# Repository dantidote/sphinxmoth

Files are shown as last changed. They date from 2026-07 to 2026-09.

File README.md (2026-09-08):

# Sphinxmoth

### The little board that answers the iSphynxII: a working flash mod for FireWire iPods (1st/2nd gen)

An **active FPGA interposer** that lets flash storage (CF, or SD behind an adapter) fully replace the 1.8″ hard drive in a **1st/2nd-generation
iPod**: boot, standalone playback, **and full-speed FireWire restore + iTunes sync**.

This is the first time in the ~25 years since these iPods shipped
that all of that works at once on flash storage. Passive adapters never could, and
it turns out they never could have. The reason was documented by Texas
Instruments in 2001.

A note on qualifications: I had none. This is the first PCB I've ever had
made, I leaned on the autorouter more than any self-respecting layout
engineer would admit, and before this project I'd never programmed an FPGA.
This board isn't pretty; it was never meant to be. It exists to answer one
question: is this possible at all?

| | |
|---|---|
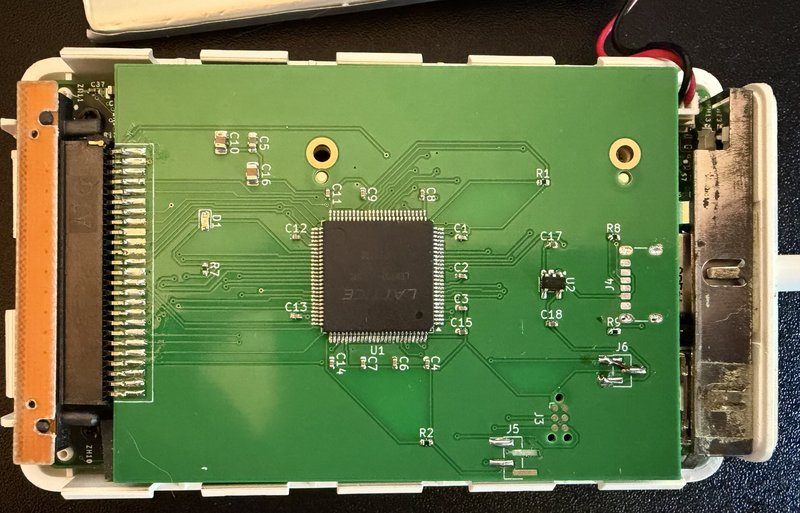
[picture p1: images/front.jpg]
front
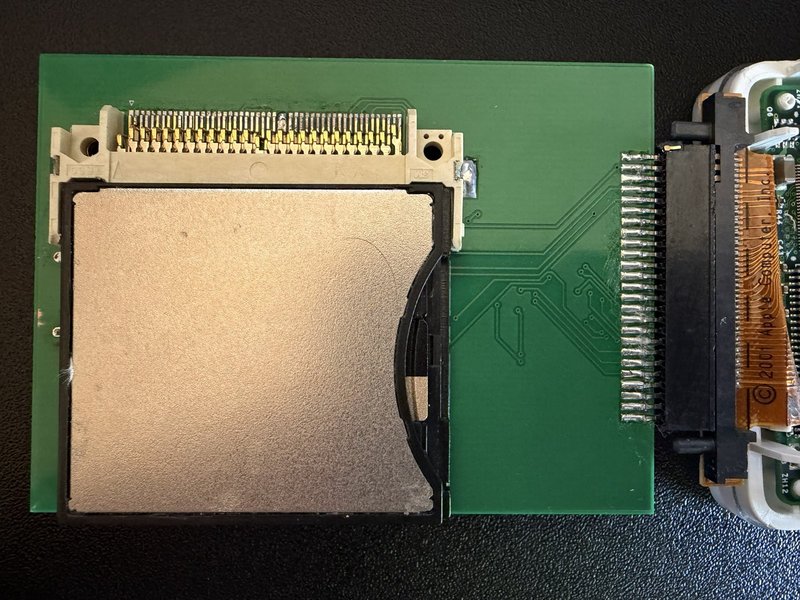
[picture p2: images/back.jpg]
back
|  |  |

*The assembled v1 board: FPGA side and CF side. And the point of it all:*

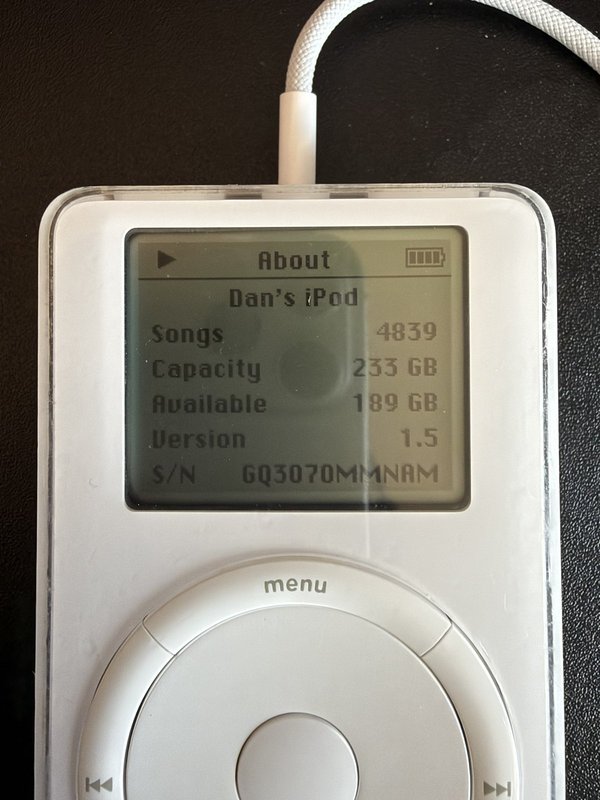
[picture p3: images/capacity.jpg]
iPod About screen: 256 GB


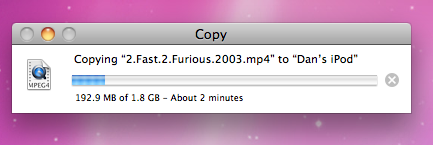
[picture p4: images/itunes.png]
Copying a 1.8 GB file to the iPod over FireWire, about 2 minutes


<p align="center"><i>A 1.8 GB file at roughly 15 MB/s over FireWire, through the bridge. No, the
1st gen can't play it. That's not the point.</i></p>

## Buying an assembled board

Sphinxmoth is open source and stays that way: the gerbers, BOM, gateware and
a hardware-validated bitstream are all in this repo, under licenses (MIT and
CERN-OHL-P-2.0) that let you build your own, and sell them if you want to.
Please do.

If you would rather not order a PCB, source a MachXO2, and go find a JTAG
probe, I sell **pre-assembled, pre-flashed boards** at
**[wunkuslabs.com](https://wunkuslabs.com/products/sphinxmoth)**.

## Why the cheap green CF/IDE adapters never worked

FireWire-era iPods (1G/2G, and the 3G) use TI's **TSB43AA82 "iSphynxII"**
FireWire-to-ATA bridge. From TI's own *TSB43AA82 Storage Reference Design*:

> It should be noted that iSphynxII does not implement the 16-bit CRC value
> required at the end of ATA ultraDMA transfers. There are two ways to deal
> with this. The first is to use HDDs that allow transfers to continue even if
> the correct CRC value is not received. The second is to insert an ASIC/PLD
> between iSphynxII and the HDD that calculates the CRC as the transfer is
> taking place and drives it to the drive at the appropriate time. This
> reference design assumes the HDD does not require the CRC.

Apple took TI's first option: the original Toshiba 1.8″ drives tolerate the
missing CRC. **Every CF card enforces it.** So the moment a flash device sees
an Ultra-DMA burst from the iSphynxII, it (correctly) rejects the transfer with
an interface-CRC error, and no passive adapter can ever fix that, because the
CRC simply isn't on the wire.

**This project is the "ASIC/PLD between iSphynxII and the HDD" that TI
described, built 25 years later.** A Lattice MachXO2 sits in the datapath,
re-originates every UDMA burst, and supplies the CRC the iSphynxII omits.

But the CRC is only the first wall. Credit to Reddit user **SquashHour9940**,
whose excellent investigation
([*Further research about flash modified iPod 1st/2nd Gen syncing problem*](https://www.reddit.com/r/ipod/comments/18fujac/further_research_about_flash_modified_ipod_1st2nd/))
independently mapped two more layers:

2. **Removable vs. fixed media**: consumer CF cards report themselves as
   *removable media*; the iPod firmware and iTunes want a *fixed disk*.
   Industrial CF cards (fixed-disk firmware) get past this gate; consumer
   cards don't.
3. **The TSB43AA82 falls back to slow PIO when it detects a CF card**:
   staged 1 MB at a time through the iPod's tiny SRAM, capping passive-adapter
   FireWire transfers around 300 KB/s even when everything else works.

And our bring-up found a fourth layer nobody had hit before, because nobody
had gotten this far:

4. **The PP5002 CPU (the retail OS) is a DMA host too**: its UDMA write
   strobes are electrically hostile (ringing, data-dependent crosstalk) and
   corrupted the filesystem on every standalone boot until this bridge learned
   to detect that master and quietly demote it to PIO.

This bridge defeats all four: it originates the missing CRC, rewrites the
card's IDENTIFY on the wire (media type and DMA capabilities, per master;
a removable or CFA-signature word 0 becomes a classic fixed-disk value,
checksum corrected), keeps the DMA path alive at full speed, and gives
each of the iPod's two very different bus masters the bus discipline it
actually needs. The fixed-disk rewrite has been tested end-to-end with a
retail Lexar Professional 800x (32 GB, UDMA 7), the exact card class the
community documented as removable-reporting: it restores and syncs
through the bridge like any industrial card.

## Status

| | |
|---|---|
| **v1 board** (CF slot, `board/`) | **Working.** Boots, plays, restores, syncs. Reads 19 MB/s, writes 4.6 MB/s over FireWire. Running a 256 GB SD (via FC1307A CF adapter) today. |
| Validated bitstream | `releases/v1.0-first-music/` (build outputs are not run-deterministic; this exact binary is the hardware-proven one) |
| **v2** (native microSD) | **Being considered.** microSD would be nice, but at first glance it needs a larger/more expensive FPGA (the v1 XO2-2000 is 89% full and the disk logic moves on-chip; the draft targets an XO2-7000). Exploratory work lives on the [`v2-native-sd`](../../tree/v2-native-sd) branch: unfabbed, unvalidated, promise-free. **Do not build it.** |

Tested on: iPod 1st gen (firmware 1.5), Transcend industrial 2 GB CF,
FC1307A SD-CF adapter + 256 GB SD, Mac OS X 10.6 + iTunes over FireWire.
2G/3G iPods use the same TSB43AA82 and *should* work; reports welcome.

## Rockbox

Rockbox runs on a Sphinxmoth iPod, with two board-specific wrinkles: the
Rockbox 4.0 release crashes at boot on every 1G/2G (an unaligned store in
the PP5002 scheduler, fixed upstream after 4.0), and Rockbox's stock IDE
timing is too fast for the `v1.1-mg132-fix3b` bridge image, which adds
about 45 ns to every register read through its PIO synchroniser (init fails
with `ATA error: -11` or `-32`). Newer bridge images pass PIO through the
raw pads and need nothing but the crash fix.

Everything Rockbox-related lives in its own repo:
[**sphinxmoth-rockbox**](https://github.com/dantidote/sphinxmoth-rockbox):
the ATA driver patch, tested builds for boards already in the field on
fix3b, and a workflow that rebuilds them on each upstream Rockbox release.
The same files are served from [wunkuslabs.com/guide](https://wunkuslabs.com/guide#rockbox).

## How it works (the short version)

The FPGA discovered during bring-up that it serves **three masters**, and it
gives each a different personality:

| Master | How it's detected | What it gets |
|---|---|---|
| **iSphynxII** (FireWire) | never issues `EXECUTE DIAGNOSTIC` | Full UDMA2 bridge: bursts re-timed through a FIFO, **end-of-burst CRC generated**, multi-burst writes, a deliberately "bouncy" flow-control throttle (it abandons bursts on long clean pauses) |
| **PP5002** (retail OS) | opens with `C90 EXECUTE DIAGNOSTIC` | IDENTIFY patched in flight (DMA capability words zeroed, checksum fixed) → the OS falls back to PIO `READ/WRITE MULTIPLE` through a transparent passthrough |
| **CF card** | n/a | Always runs UDMA2, regardless of what either host negotiated (`SET FEATURES` sector-count byte rewritten on the wire) |

Plus the small in-flight surgeries each master demanded: BSY served for status
polls mid-command, CS/DA forced idle at the card during bridged bursts, strict
data setup/hold on every strobe edge, spec-ordered burst termination, and
STANDBY/SLEEP commands rewritten to CHECK POWER MODE (retail cards honor them,
then never wake the way the OS expects; the original drive woke transparently). The
testbenches encode all of it: the card model sector-terminates, pauses,
checks CRC and enforces tSS; the host model parks on the status register,
polls, and rings its strobe line. Every cruelty in the sims reproduced a bug
first found on real hardware during a two-day, fourteen-bug bring-up.

## Building it

Or skip it: assembled, flashed and tested boards are
[for sale](https://wunkuslabs.com/products/sphinxmoth).

**Board (v1):** upload `board/ipod-cf-udma-gerbers.zip` to any fab (2 layer,
53×72 mm, 1.6 or 0.8 mm). CF socket (J2) is on the BACK; everything else on
the front. `board/BOM.csv` + `board/ipod-cf-udma-pos.csv` for assembly.

**Bitstream:** Lattice Diamond 3.14, `cd diamond && pnmainc rebuild.tcl` →
`impl1/ipodboard_impl1.jed`. Or just flash `releases/v1.0-first-music/`.

**Programming:** Tag-Connect TC2030-IDC-NL pads (J3, zero height) to any
JTAG probe Diamond Programmer / openFPGALoader speaks. The MachXO2 configures
from internal flash; program once, done.

**Power:** bus-powered from the iPod's 3.3 V. J6 shunt selects iPod (1-2) or
bench USB-C (2-3); never both. The green LED blips a slow heartbeat when idle
and flashes while data is moving through the bridge. The UART header (J5, 115200 8N1) streams the
gateware's event log; if something misbehaves, that log is the microscope
this whole project was debugged through.

**Simulation:** Icarus Verilog: `cd gateware && iverilog -g2012 -DSIM -I rtl
-o wr.vvp sim/tb_full_write.v rtl/*.v && vvp wr.vvp` (likewise
`tb_full_read.v`).

## Repository layout

| Path | Contents |
|---|---|
| `board/` | v1 board: KiCad project, fabbed gerbers, BOM, schematic PDF, DRC/ERC |
| `gateware/rtl/` | the bridge RTL (`interposer_top` + engines) |
| `gateware/sim/` | hardware-calibrated torture testbenches |
| `diamond/` | Lattice Diamond build project |
| `releases/` | hardware-validated bitstreams |
| `v2-native-sd` branch | exploratory native-microSD v2: board draft, `ata_device`/`sd_host` cores, design doc |

## Known v1 errata

- J2 pin 39 (−CSEL) must be grounded (already fixed in these gerbers).
- J2 pins 45/46 (−DASP/−PDIAG) float; some cards may care (10 k pull-ups to
  3.3 V recommended).
- The USB-C shield holes share the CF socket's courtyard; desoldering J4
  heat-stresses socket joints (ask us how we know). v2 deletes both parts.
- DD-bus ↔ control-line crosstalk exists at the margins; the gateware routes
  around it (PIO for the PP5002), v2 adds proper guarding.

## Credits

- **SquashHour9940** (r/ipod): the fixed-disk/removable-media and
  TSB43AA82-PIO-fallback research that mapped layers 2 and 3:
  https://www.reddit.com/r/ipod/comments/18fujac/further_research_about_flash_modified_ipod_1st2nd/
- Texas Instruments, for documenting in 2001 exactly which chip to blame
  and exactly what to build about it.
- [freerouting](https://github.com/freerouting/freerouting): the open-source
  autorouter that closed every net on both boards.

## License

Gateware and software: MIT. Hardware (schematics, board files, gerbers):
CERN-OHL-P-2.0. No warranty; a 25-year-old iPod is involved.

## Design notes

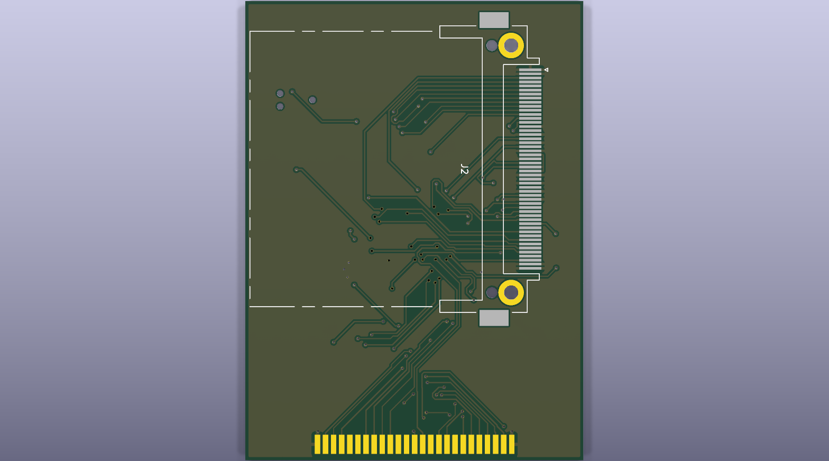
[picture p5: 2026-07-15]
board/board_bottom.png

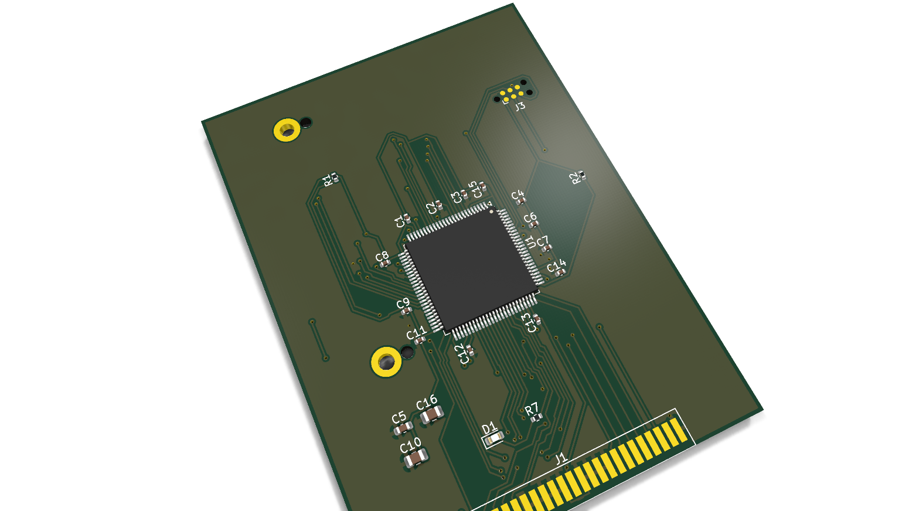
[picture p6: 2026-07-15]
board/board_persp.png

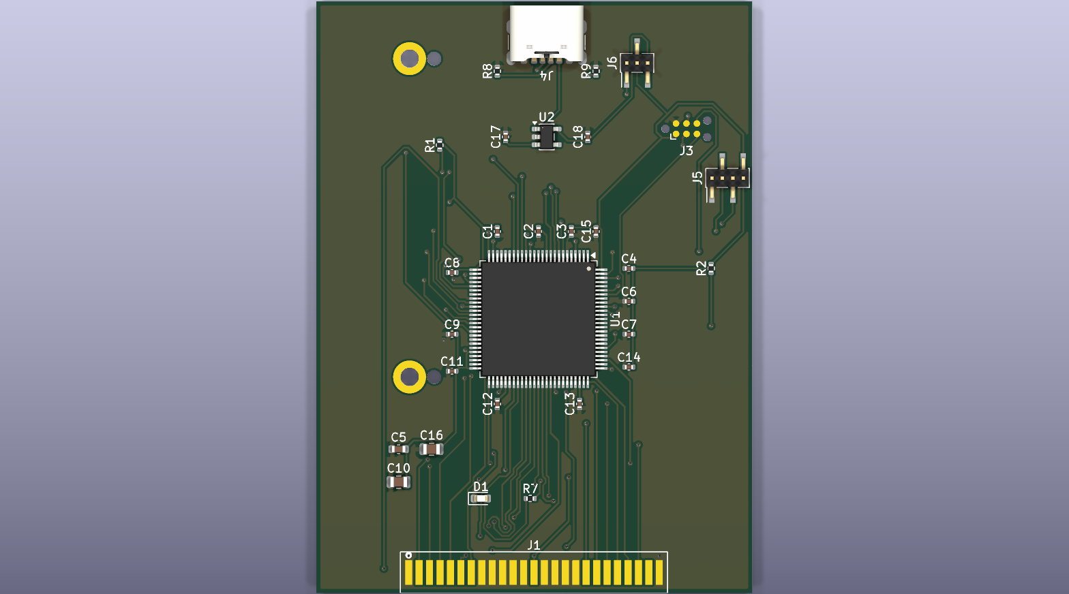
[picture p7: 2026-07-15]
board/board_top.png

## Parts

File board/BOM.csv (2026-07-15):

Refs | Value | Footprint | MPN | Qty
C1-C4,C6-C9,C11-C14 | 100nF | Capacitor_SMD:C_0402_1005Metric | CL05B104KO5NNNC | 12
C5 | 4.7uF | Capacitor_SMD:C_0603_1608Metric | CL10A475KO8NNNC | 1
C10,C16 | 10uF | Capacitor_SMD:C_0805_2012Metric | C2012X5R1E106K125AB | 2
C15,C17,C18 | 1uF | Capacitor_SMD:C_0402_1005Metric | CL05A105KA5NNNC | 3
D1 | LED | LED_SMD:LED_0603_1608Metric | 150060GS75000 | 1
J1 | iPod_1.8in_50pin | interposer:iPod_1.8in_50pin | SPECIALTY-iPod-1.8in-50pin | 1
J2 | CF True-IDE socket | Connector_Card:CF-Card_3M_N7E50-E516xx-30 | N7E50-E516PK-30 | 1
J4 | USB-C | Connector_USB:USB_C_Receptacle_GCT_USB4125-xx-x_6P_TopMnt_Horizontal | USB4125-GF-A-0190 | 1
R1,R2 | 10k | Resistor_SMD:R_0402_1005Metric | CRCW040210K0FKED | 2
R7 | 330R | Resistor_SMD:R_0402_1005Metric | RC0402FR-07330RL | 1
R8,R9 | 5.1k | Resistor_SMD:R_0402_1005Metric | RC0402FR-075K1L | 2
U1 | LCMXO2-2000HC-4TG100C | Package_QFP:TQFP-100_14x14mm_P0.5mm | LCMXO2-2000HC-4TG100C | 1
U2 | AP2112K-3.3 | Package_TO_SOT_SMD:SOT-23-5 | AP2112K-3.3TRG1 | 1

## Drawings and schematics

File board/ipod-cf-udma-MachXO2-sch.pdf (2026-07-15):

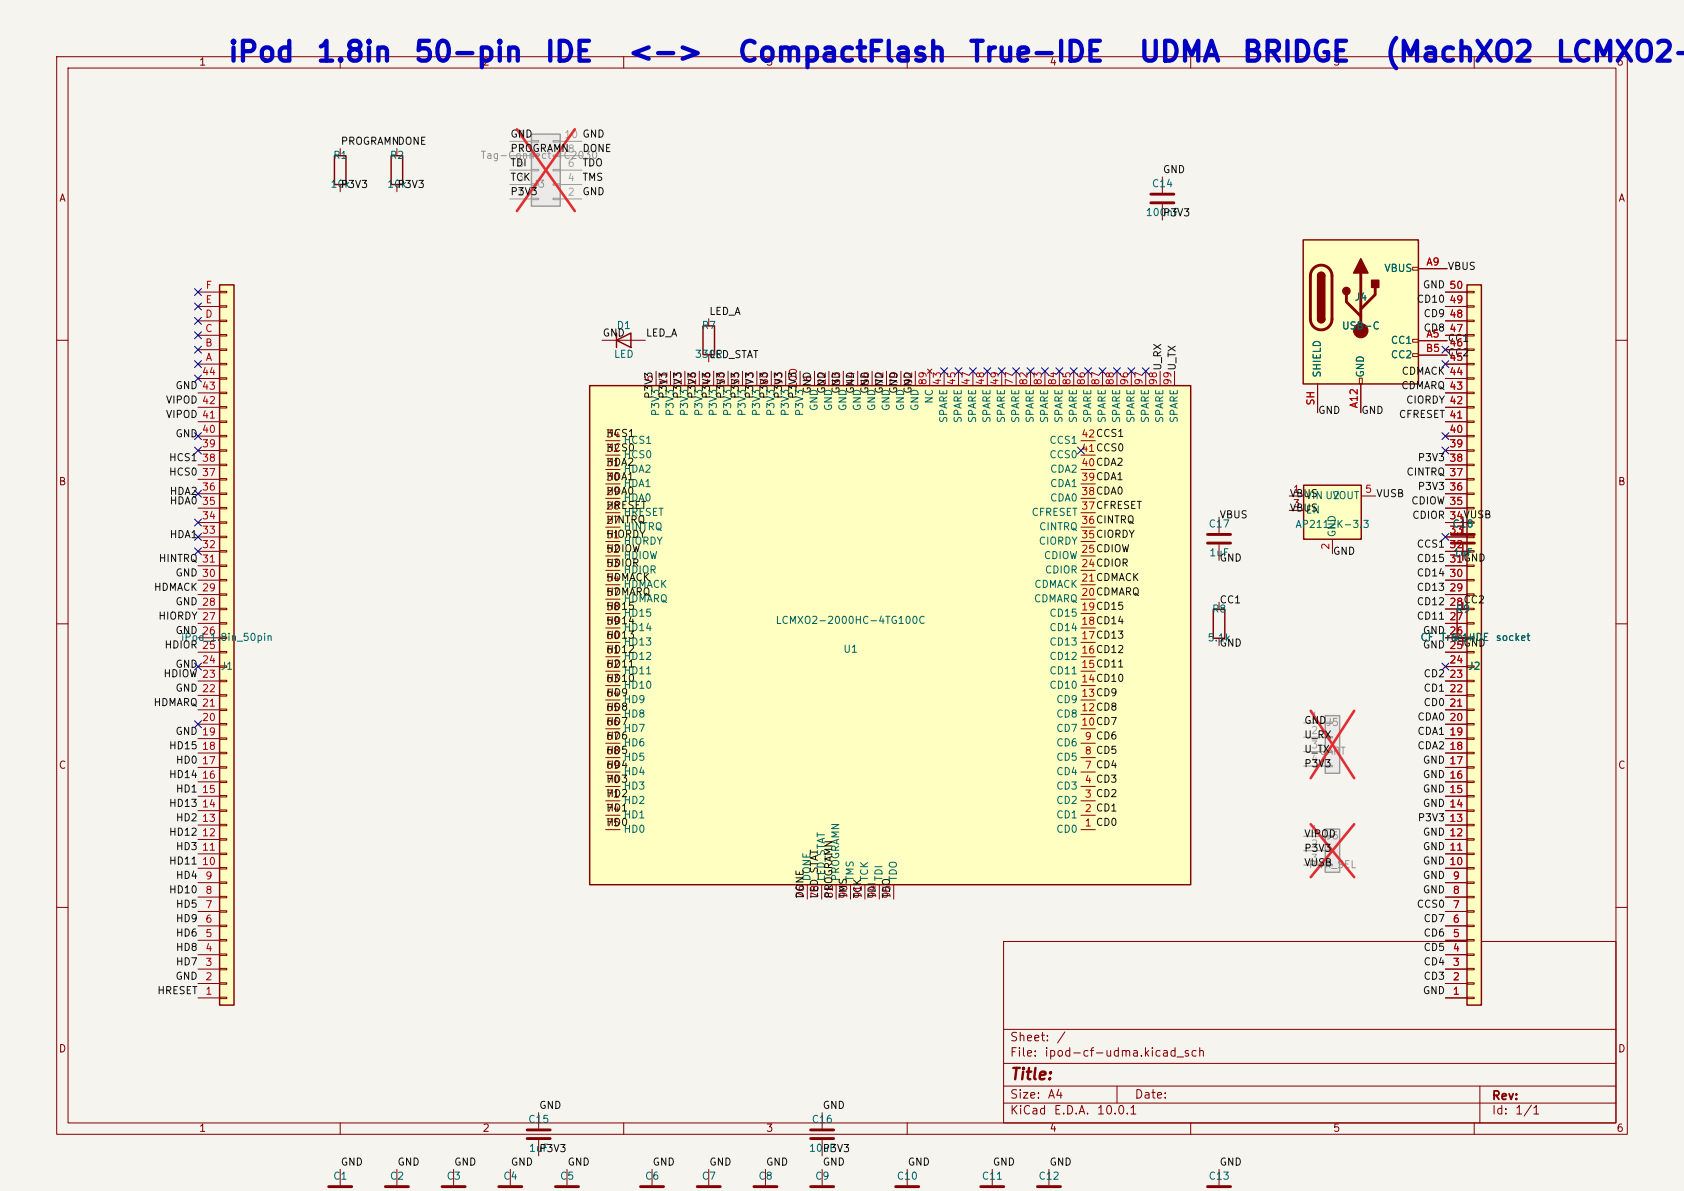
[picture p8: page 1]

iPod 1.8in 50-pin IDE <-> CompactFlash True-IDE UDMA BRIDGE (MachXO2 LCMXO2-2000HC-TG100)

GND
CCS0 GND HD1 HD0 GND
HCS1
CD12 CD13 CD14 UDMA / CRC: U1 (MachXO2) actively re-times the bus and is the device the iPod talks to. The FPGA HDL terminates the host UDMA burst, and on writes may IGNORE / force-OK the host-supplied CRC while regenerating a correct CRC toward the CF card. A purely passive adapter CANNOT do this - that is why an FPGA sits in the datapath.
HDIOW

6 CD4 7 CD5 8 CD6 9 CD7 10 P3V3 11 CD8 12 CD9 13 CD10 14 CD11 15 CD12 16 CD13 17 CD14 18 CD15 19 CDMARQ 20 CDMACK 21 GND 22 P3V3 23 CDIOR 24 CDIOW 25 P3V3 26 HINTRQ 27 HRESET 28 HDA0 29 HDA1 30 HDA2 31 HCS0 32 GND 33 HCS1 34 CIORDY 35 CINTRQ 36 CFRESET 37 CDA0 38 CDA1 39 CDA2 40 CCS0 41 CCS1 42 SPARE 43 GND 44 SPARE 45 P3V3 46 SPARE 47 SPARE 48 SPARE 49 P3V3 50 HIORDY 51 HDIOW 52 HDIOR 53 HDMACK 54 P3V3 55 GND 56 HDMARQ 57 HD15 58 HD14 59 HD13 60 HD12 61 HD11 62 HD10 63 HD9 64 HD8 65 HD7 66 HD6 67 HD5 68 HD4 69 HD3 70 HD2 71 GND 72 P3V3 73 HD1 74 HD0 75 DONE 76 SPARE 77 LED_STAT 78 GND 79 P3V3 80 PROGRAMN 81 SPARE 82 SPARE 83 SPARE 84 SPARE 85 SPARE 86 SPARE 87 SPARE 88 NC 89 TMS 90 TCK 91 GND 92 P3V3 93 TDI 94 TDO 95 SPARE 96 SPARE 97 SPARE 98 SPARE 99 P3V3100 U1
HCS0 HCS1 P3V3 P3V3

HD0 HD1 HD2 HD3 HD4 HD5 HD6 HD7 HD8 HD9 HDIOR HIORDY HDMACK HINTRQ

J2 CF True-IDE socket PWR1 PWR_FLAG

Sheet: /
File: ipod-cf-udma.kicad_sch
Title:

Size: A4 | Rev:
KiCad E.D.A. 10.0.1 | Id: 1/1

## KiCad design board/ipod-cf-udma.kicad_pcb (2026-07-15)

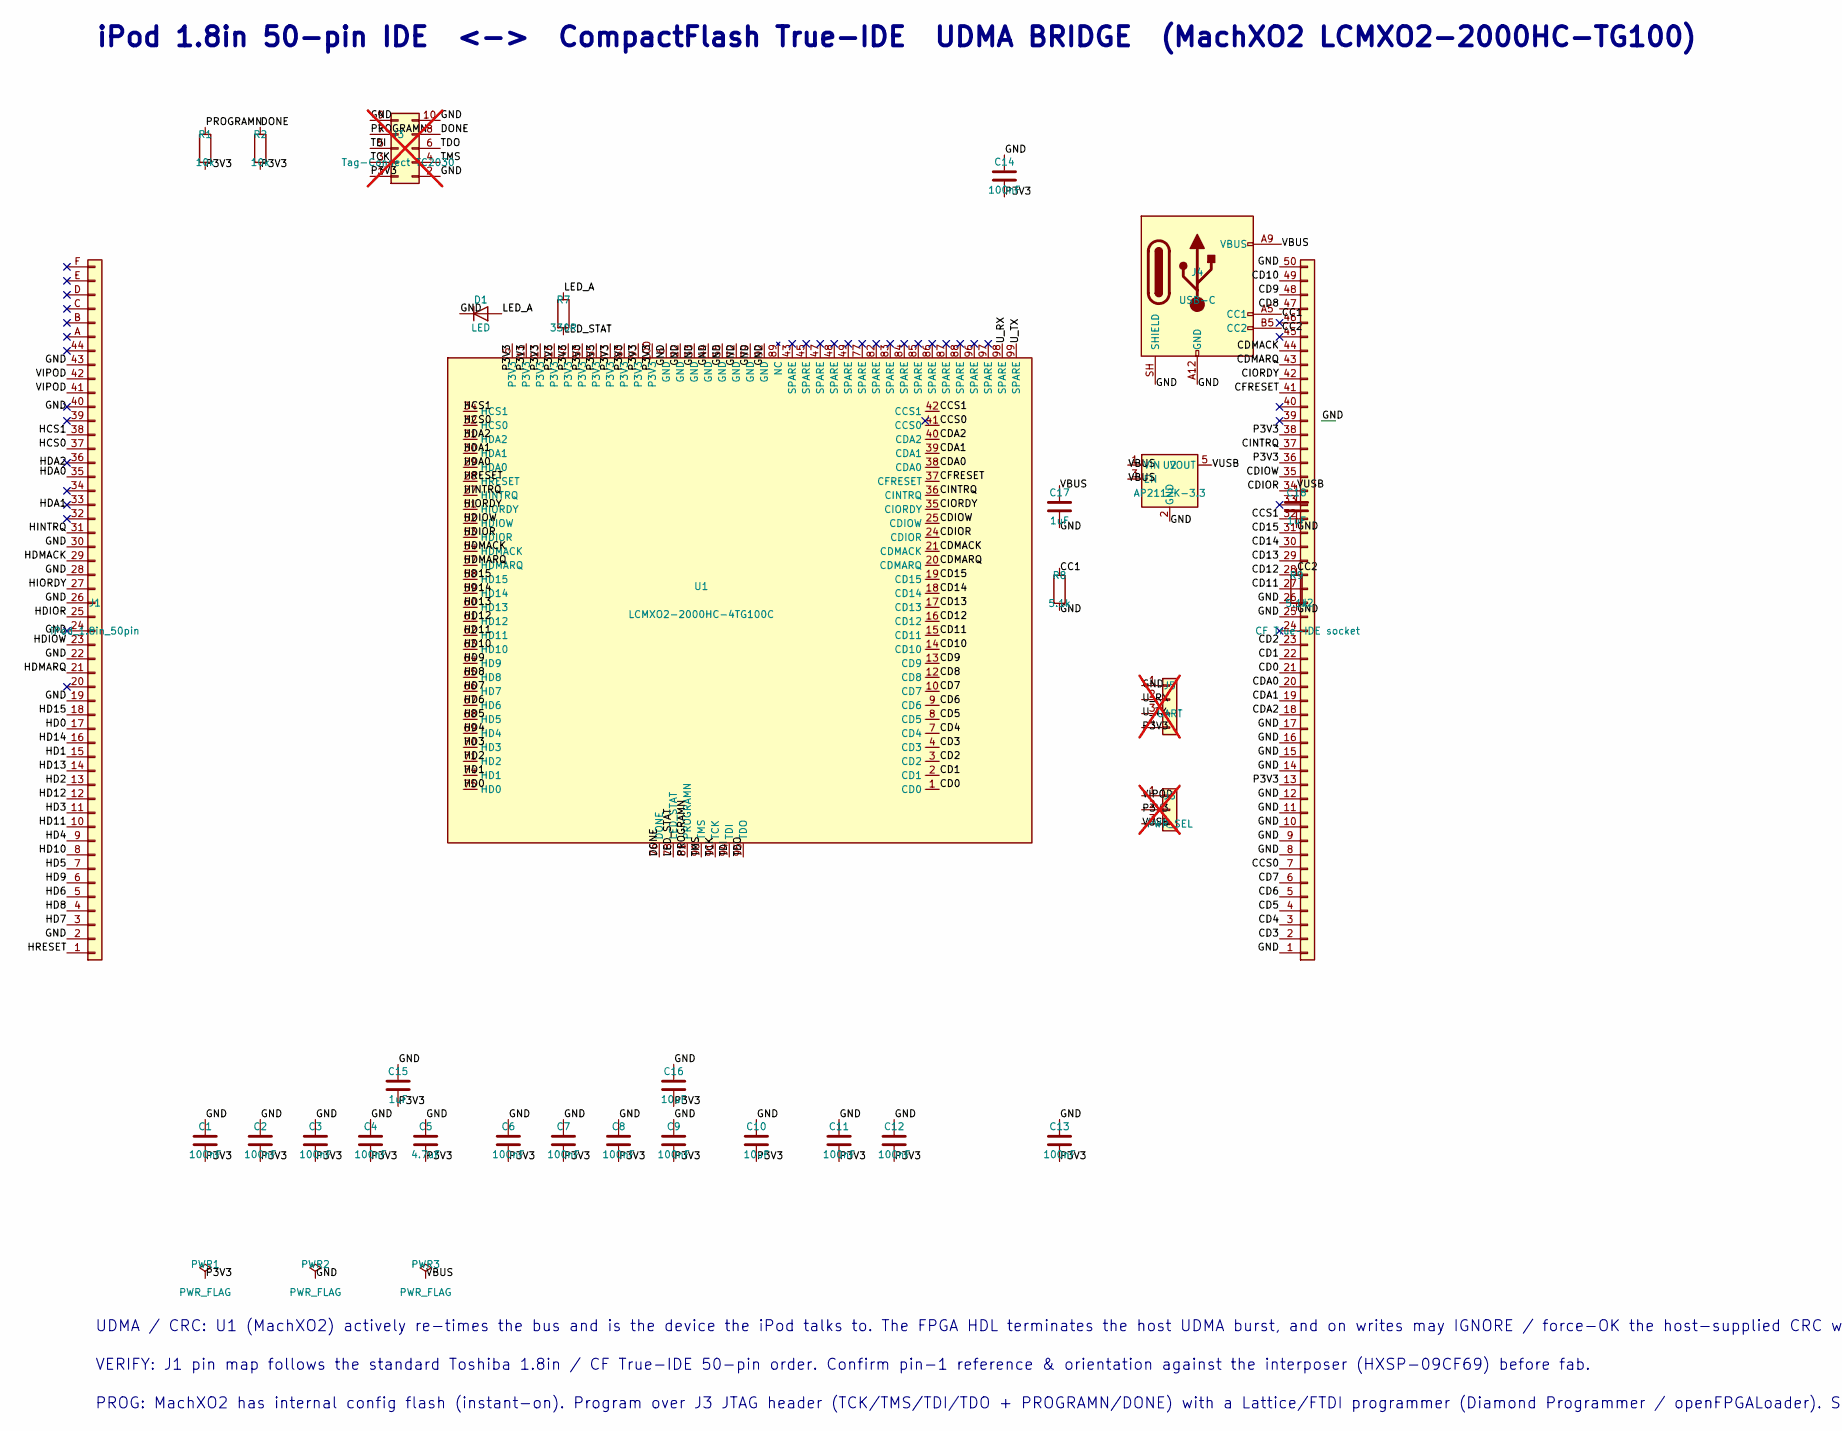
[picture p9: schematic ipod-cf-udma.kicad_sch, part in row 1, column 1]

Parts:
C1, C2, C3, C4, C6, C7, C8, C9, C11, C12, C13, C14: 100nF; C_0402_1005Metric; MPN CL05B104KO5NNNC
C5: 4.7uF; C_0603_1608Metric; MPN CL10A475KO8NNNC
C10, C16: 10uF; C_0805_2012Metric; MPN C2012X5R1E106K125AB
C15, C17, C18: 1uF; C_0402_1005Metric; MPN CL05A105KA5NNNC
D1: LED; LED_0603_1608Metric; MPN 150060GS75000
J1: iPod_1.8in_50pin; MPN SPECIALTY-iPod-1.8in-50pin
J2: CF True-IDE socket; CF-Card_3M_N7E50-E516xx-30; MPN N7E50-E516PK-30
J3: Tag-Connect TC2030; Tag-Connect_TC2030-IDC-NL_2x03_P1.27mm_Vertical; MPN DNP-padsonly; not fitted
J4: USB-C; USB_C_Receptacle_GCT_USB4125-xx-x_6P_TopMnt_Horizontal; MPN USB4125-GF-A-0190
J5: UART; PinHeader_1x04_P1.27mm_Vertical_SMD_Pin1Left; MPN DNP-optional-header; not fitted
J6: PWR_SEL; PinHeader_1x03_P1.27mm_Vertical_SMD_Pin1Left; MPN DNP-solderjumper; not fitted
PWR1, PWR2, PWR3: PWR_FLAG
R1, R2: 10k; R_0402_1005Metric; MPN CRCW040210K0FKED
R7: 330R; R_0402_1005Metric; MPN RC0402FR-07330RL
R8, R9: 5.1k; R_0402_1005Metric; MPN RC0402FR-075K1L
U1: LCMXO2-2000HC-4TG100C; TQFP-100_14x14mm_P0.5mm; MPN LCMXO2-2000HC-4TG100C
U2: AP2112K-3.3; SOT-23-5; MPN AP2112K-3.3TRG1

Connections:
CC1: J4.A5 (CC1), R8.1
CC2: J4.B5 (CC2), R9.1
CCS0: J2.7, U1.41 (CCS0)
CCS1: J2.32, U1.42 (CCS1)
CD0: J2.21, U1.1 (CD0)
CD1: J2.22, U1.2 (CD1)
CD2: J2.23, U1.3 (CD2)
CD3: J2.2, U1.4 (CD3)
CD4: J2.3, U1.7 (CD4)
CD5: J2.4, U1.8 (CD5)
CD6: J2.5, U1.9 (CD6)
CD7: J2.6, U1.10 (CD7)
CD8: J2.47, U1.12 (CD8)
CD9: J2.48, U1.13 (CD9)
CD10: J2.49, U1.14 (CD10)
CD11: J2.27, U1.15 (CD11)
CD12: J2.28, U1.16 (CD12)
CD13: J2.29, U1.17 (CD13)
CD14: J2.30, U1.18 (CD14)
CD15: J2.31, U1.19 (CD15)
CDA0: J2.20, U1.38 (CDA0)
CDA1: J2.19, U1.39 (CDA1)
CDA2: J2.18, U1.40 (CDA2)
CDIOR: J2.34, U1.24 (CDIOR)
CDIOW: J2.35, U1.25 (CDIOW)
CDMACK: J2.44, U1.21 (CDMACK)
CDMARQ: J2.43, U1.20 (CDMARQ)
CFRESET: J2.41, U1.37 (CFRESET)
CINTRQ: J2.37, U1.36 (CINTRQ)
CIORDY: J2.42, U1.35 (CIORDY)
DONE: J3.8, R2.1, U1.76 (DONE)
GND: C1.1, C2.1, C3.1, C4.1, C5.1, C6.1, C7.1, C8.1, C9.1, C10.1, C11.1, C12.1, C13.1, C14.1, C15.1, C16.1, C17.2, C18.2, D1.1 (K), J1.2, J1.19, J1.22, J1.24, J1.26, J1.28, J1.30, J1.40, J1.43, J2.1, J2.8, J2.9, J2.10, J2.11, J2.12, J2.14, J2.15, J2.16, J2.17, J2.25, J2.26, J2.39, J2.50, J3.2, J3.9, J3.10, J4.A12 (GND), J4.B12 (GND), J4.SH (SHIELD), J5.1, PWR2.1, R8.2, R9.2, U1.6 (GND), U1.22 (GND), U1.33 (GND), U1.44 (GND), U1.56 (GND), U1.72 (GND), U1.79 (GND), U1.92 (GND), U2.2 (GND)
HCS0: J1.37, U1.32 (HCS0)
HCS1: J1.38, U1.34 (HCS1)
HD0: J1.17, U1.75 (HD0)
HD1: J1.15, U1.74 (HD1)
HD2: J1.13, U1.71 (HD2)
HD3: J1.11, U1.70 (HD3)
HD4: J1.9, U1.69 (HD4)
HD5: J1.7, U1.68 (HD5)
HD6: J1.5, U1.67 (HD6)
HD7: J1.3, U1.66 (HD7)
HD8: J1.4, U1.65 (HD8)
HD9: J1.6, U1.64 (HD9)
HD10: J1.8, U1.63 (HD10)
HD11: J1.10, U1.62 (HD11)
HD12: J1.12, U1.61 (HD12)
HD13: J1.14, U1.60 (HD13)
HD14: J1.16, U1.59 (HD14)
HD15: J1.18, U1.58 (HD15)
HDA0: J1.35, U1.29 (HDA0)
HDA1: J1.33, U1.30 (HDA1)
HDA2: J1.36, U1.31 (HDA2)
HDIOR: J1.25, U1.53 (HDIOR)
HDIOW: J1.23, U1.52 (HDIOW)
HDMACK: J1.29, U1.54 (HDMACK)
HDMARQ: J1.21, U1.57 (HDMARQ)
HINTRQ: J1.31, U1.27 (HINTRQ)
HIORDY: J1.27, U1.51 (HIORDY)
HRESET: J1.1, U1.28 (HRESET)
LED_A: D1.2 (A), R7.1
LED_STAT: R7.2, U1.78 (LED_STAT)
P3V3: C1.2, C2.2, C3.2, C4.2, C5.2, C6.2, C7.2, C8.2, C9.2, C10.2, C11.2, C12.2, C13.2, C14.2, C15.2, C16.2, J2.13, J2.36, J2.38, J3.1, J5.4, J6.2, PWR1.1, R1.2, R2.2, U1.5 (P3V3), U1.11 (P3V3), U1.23 (P3V3), U1.26 (P3V3), U1.46 (P3V3), U1.50 (P3V3), U1.55 (P3V3), U1.73 (P3V3), U1.80 (P3V3), U1.93 (P3V3), U1.100 (P3V3)
PROGRAMN: J3.7, R1.1, U1.81 (PROGRAMN)
TCK: J3.3, U1.91 (TCK)
TDI: J3.5, U1.94 (TDI)
TDO: J3.6, U1.95 (TDO)
TMS: J3.4, U1.90 (TMS)
U_RX: J5.2, U1.98 (SPARE)
U_TX: J5.3, U1.99 (SPARE)
VBUS: C17.1, J4.A9 (VBUS), J4.B9 (VBUS), PWR3.1, U2.1 (VIN), U2.3 (EN)
VIPOD: J1.41, J1.42, J6.1
VUSB: C18.1, J6.3, U2.5 (VOUT)

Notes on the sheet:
iPod 1.8in 50-pin IDE <-> CompactFlash True-IDE UDMA BRIDGE (MachXO2 LCMXO2-2000HC-TG100)
UDMA / CRC: U1 (MachXO2) actively re-times the bus and is the device the iPod talks to. The FPGA HDL terminates the host UDMA burst, and on writes may IGNORE / force-OK the host-supplied CRC while regenerating a correct CRC toward the CF card. A purely passive adapter CANNOT do this - that is why a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
VERIFY: J1 pin map follows the standard Toshiba 1.8in / CF True-IDE 50-pin order. Confirm pin-1 reference & orientation against the interposer (HXSP-09CF69) before fab.
PROG: MachXO2 has internal config flash (instant-on). Program over J3 JTAG header (TCK/TMS/TDI/TDO + PROGRAMN/DONE) with a Lattice/FTDI programmer (Diamond Programmer / openFPGALoader). Single 3.3V rail, bus-powered from host (J1.13/38). I/O pin assignment is a starting point - lock final pins in D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

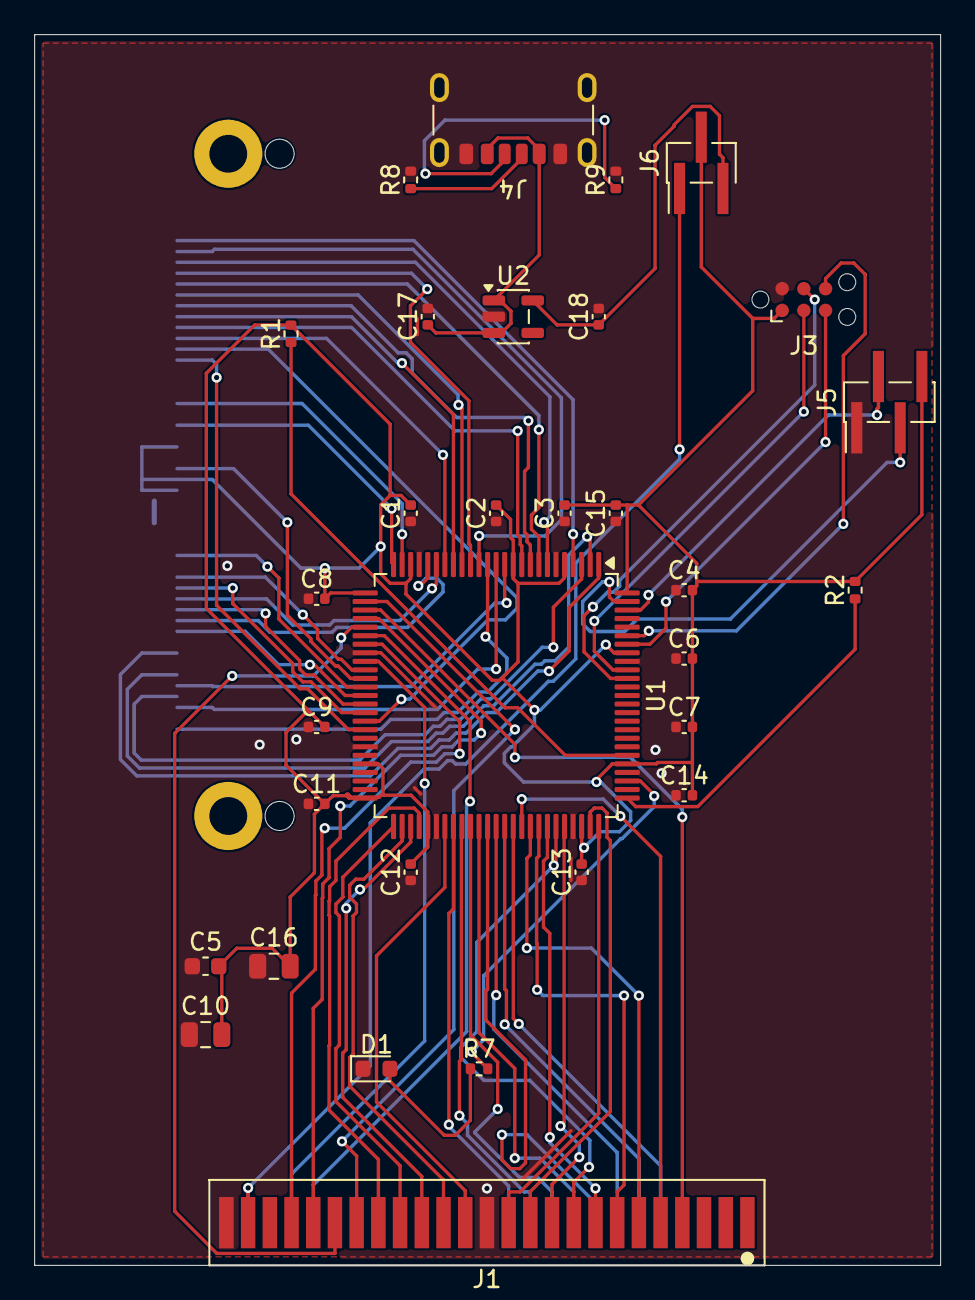
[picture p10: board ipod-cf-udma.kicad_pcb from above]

Board: 2 copper layers, 53.0 x 72.0 mm, 32 parts (1 on the bottom side), 73 nets.

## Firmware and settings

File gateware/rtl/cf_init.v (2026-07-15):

// ============================================================================
// cf_init.v -- post-reset CF mode fixup. The iSphynx never issues SET FEATURES
// (the original Toshiba drive powers up with UDMA2 already selected), so after
// every CF reset WE select UDMA2 on the card: SET FEATURES 03h, count 42h.
// While `active`, the top holds the host off with BSY and we own the CF bus.
// ============================================================================

module cf_init #(
    parameter CLK_MHZ = 66
) (
    input             clk,
    input             rst_n,        // includes host reset: re-arms on every reset

    output reg        active,       // we own the CF bus / host sees BSY
    output reg        rst_drive,    // assert CF_RESET_N low (clean post-power reset)

    // CF bus (valid while active)
    output reg        cs0_n,
    output reg [2:0]  addr,
    output reg        ior_n,
    output reg        iow_n,
    output reg [15:0] dd_out,
    output reg        dd_oe,
    input      [15:0] dd_in,        // synced CF_DD

    output reg        done_ev,      // 1-cycle: mode set, card ready
    output reg        fail_ev,      // 1-cycle: gave up (timeout)
    output reg [7:0]  last_status   // final CF status we saw
);

    // ---- single PIO cycle (slow, mode-0-ish) ----
    localparam XC_SETUP = 8'd12, XC_STROBE = 8'd40, XC_HOLD = 8'd8, XC_REC = 8'd20;   // ticks @66.5MHz
    reg        xgo, xop;            // op: 0=read 1=write
    reg  [2:0] xaddr;
    reg [15:0] xwdata, xrdata;
    reg        xbusy;
    reg  [7:0] xc;
    reg  [2:0] xs;
    localparam X_IDLE=0, X_SETUP=1, X_STROBE=2, X_HOLD=3, X_REC=4;

    always @(posedge clk or negedge rst_n) begin
        if (!rst_n) begin
            xs <= X_IDLE; xbusy <= 0; xc <= 0;
            cs0_n <= 1'b1; ior_n <= 1'b1; iow_n <= 1'b1; addr <= 3'd0;
            dd_oe <= 1'b0; dd_out <= 16'h0; xrdata <= 16'h0;
        end else begin
            case (xs)
            X_IDLE: if (xgo) begin
                xbusy <= 1'b1; cs0_n <= 1'b0; addr <= xaddr;
                if (xop) begin dd_out <= xwdata; dd_oe <= 1'b1; end
                xc <= XC_SETUP; xs <= X_SETUP;
            end
            X_SETUP: if (xc==0) begin
                if (xop) iow_n <= 1'b0; else ior_n <= 1'b0;
                xc <= XC_STROBE; xs <= X_STROBE;
            end else xc <= xc - 1'b1;
            X_STROBE: if (xc==0) begin
                if (!xop) xrdata <= dd_in;
                ior_n <= 1'b1; iow_n <= 1'b1;
                xc <= XC_HOLD; xs <= X_HOLD;
            end else xc <= xc - 1'b1;
            X_HOLD: if (xc==0) begin
                cs0_n <= 1'b1; dd_oe <= 1'b0;
                xc <= XC_REC; xs <= X_REC;
            end else xc <= xc - 1'b1;
            X_REC: if (xc==0) begin xbusy <= 1'b0; xs <= X_IDLE; end
                   else xc <= xc - 1'b1;
            default: xs <= X_IDLE;
            endcase
        end
    end

    // ---- sequencer ----
    // wait 2ms after reset -> clean 1ms CF reset pulse -> poll status (2ms
    // cadence) until ready -> Features=03 -> Count -> Command=EF -> poll -> done
    localparam T_2MS   = 24'd133000;  // @66.5MHz
    localparam T_1MS   = 24'd66500;
    localparam BUDGET1 = 15'd2500;    // 2500 * 2ms = 5s: cards init <1s; short
                                      // enough that a no-card boot fails fast
    localparam BUDGET2 = 15'd50;      // 100ms

    localparam I_WAIT=0, I_PGO=1, I_PWAIT=2, I_PEVAL=3,
               I_F=4, I_FW=5, I_C=6, I_CW=7, I_E=8, I_EW=9,
               I_P2GO=10, I_P2W=11, I_P2EVAL=12, I_END=13,
               I_SG2=14, I_SG2W=15, I_SG3=16, I_SG3W=17,
               I_SG4=18, I_SG4W=19, I_SG5=20, I_SG5W=21,
               I_DGO=22, I_DW=23, I_RST0=24, I_RST=25;
    reg [4:0]  is_;
    reg [23:0] tick;
    reg [14:0] budget;
    reg [2:0]  dump_idx;   // fail autopsy: regs 1..6 (err, SC, LBA0/1/2, dev)
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

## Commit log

2026-07-15 Sphinxmoth: the FireWire iPod flash mod that finally works
    An active MachXO2 interposer between the iPod 1G/2G's 50-pin drive header
    and a CompactFlash card. The TSB43AA82 (iSphynxII) FireWire-ATA bridge in
    these iPods omits the UDMA end-of-burst CRC (documented in TI's own
    Storage Reference Design, which suggests exactly this device: "an
    ASIC/PLD between iSphynxII and the HDD"); the original Toshiba drives
    tolerate that, flash cards do not. This bridge re-originates every UDMA
    burst with a correct CRC, patches IDENTIFY per bus master, and gives each
    of the iPod's two very different ATA hosts the bus discipline it needs.
    Result: boot, standalone playback, and full-speed FireWire restore/sync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
    [BOM.csv, ipod-cf-udma.kicad_pcb, ipod-cf-udma.kicad_sch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]
2026-08-21 README: point at assembled boards
    The repo has everything needed to build one, but "order a PCB, source a
    MachXO2, find a JTAG probe" is a real barrier. Say plainly that the design
    stays open and that assembled, flashed boards are also for sale.
2026-09-08 rockbox: source patch for fix3b boards + workflow that builds it on upstream releases
    pp5002-sphinxmoth.patch makes Rockbox's PP5002 ATA driver select the IDE
    timing by CPU clock (the retail firmware's values) and pace PIO data writes
    on the controller idle bit, so stock-timing failures on the fix3b bridge
    image (ATA error -11/-32 at init, -4 on every write) go away without a
    patched binary per release.
    The workflow builds ipod1g2g and ipod3g with the patch applied: weekly for
    the newest upstream release tag not yet published here, or on demand for
    any ref. The arm-elf-eabi toolchain from tools/rockboxdev.sh is cached.
    Output is published as a GitHub release "rockbox-<tag>-sphinxmoth". Buil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
2026-09-08 Move Rockbox material to its own repo; keep this one gerbers and gateware
    The patch, builds and workflow merged in #1 now live at
    github.com/dantidote/sphinxmoth-rockbox, where Rockbox releases can track
    upstream without mixing with gateware releases. Remove them here and add a
    short Rockbox section to the README pointing at that repo and the guide.
